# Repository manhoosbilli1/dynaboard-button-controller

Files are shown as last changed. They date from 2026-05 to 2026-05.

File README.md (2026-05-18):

# DynaButton

Dynaboard - STM32F103 multi-button HID/control interface with USB-C and high-density I/O

## At a Glance

- **Status**: Routed
- **Board size**: 48.31 x 52.88 mm
- **Layers**: 4
- **Components**: 68
- **Key ICs**:
  - U1: STM32F103C8T6
  - U2: U_REG LD1117S50TR_SOT223
  - U3: AMS1117
  - U4: 74LVC2G241

## Schematic

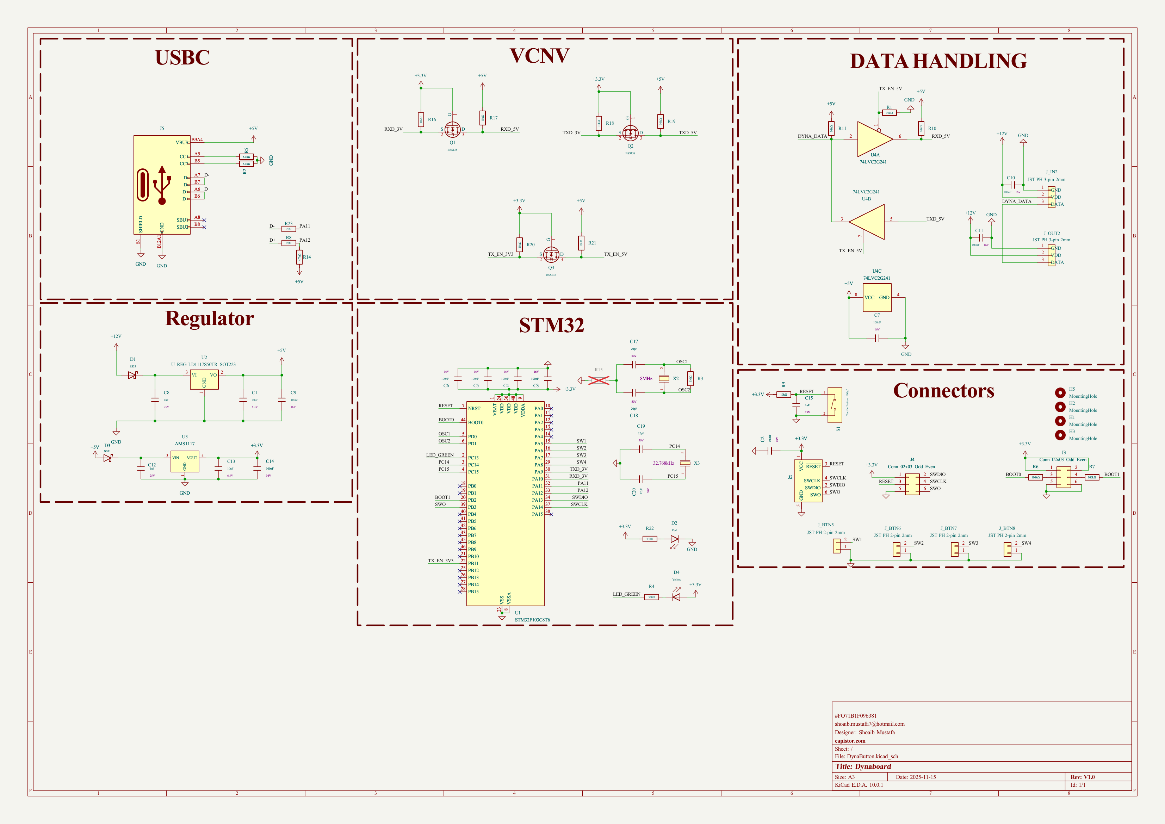
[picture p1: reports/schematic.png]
Schematic


Full PDF: [reports/schematic.pdf](reports/schematic.pdf)

## Component Roles

- **STM32F103C8T6** (U1) - main MCU (ARM Cortex-M3, 72 MHz); handles button matrix scanning and USB HID
- **74LVC2G241** (U4) - dual buffer/line driver for clean digital I/O signaling on the button outputs
- **LD1117S50TR** (U2) - 5 V LDO for peripheral rail
- **AMS1117** (U3) - 3.3 V LDO for the STM32 core
- **BSS138** x3 (Q1-Q3) - small-signal N-MOSFETs for level shifting / open-drain signaling between 3.3 V MCU and 5 V peripherals
- **X50328MSB2GI** - 8 MHz crystal for STM32 system clock
- **USB-Type-C 16-pin** connector for power + data
- **SS33 Schottky** x2 (D1, D3) - reverse-polarity protection / freewheel diodes
- **JST-PH 2 mm** connectors for daisy-chained external buttons (J_BTN5-J_BTN8) and pass-through I/O (J_IN2, J_OUT2)

## PCB

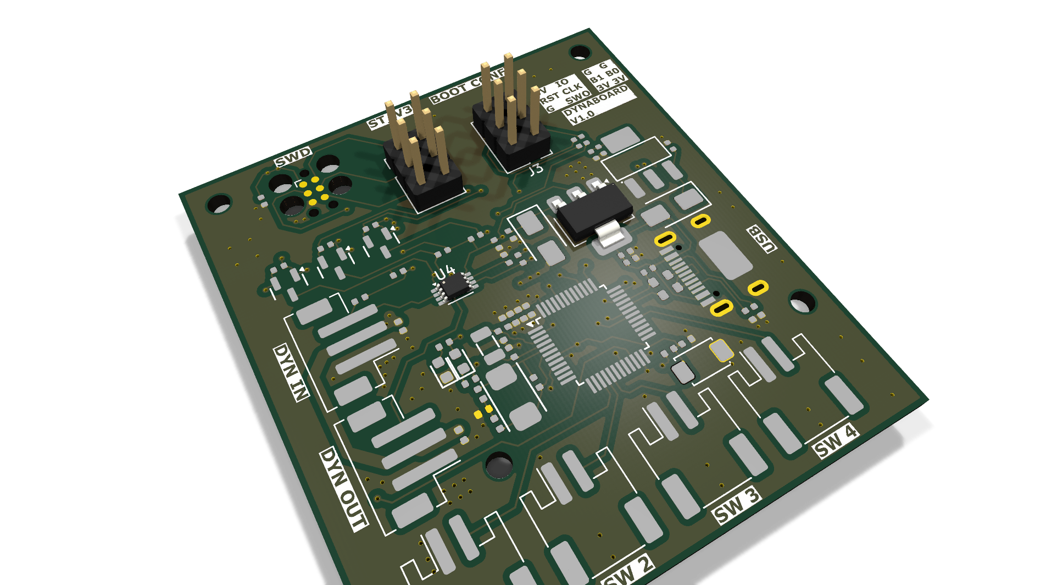
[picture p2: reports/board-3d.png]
3D top


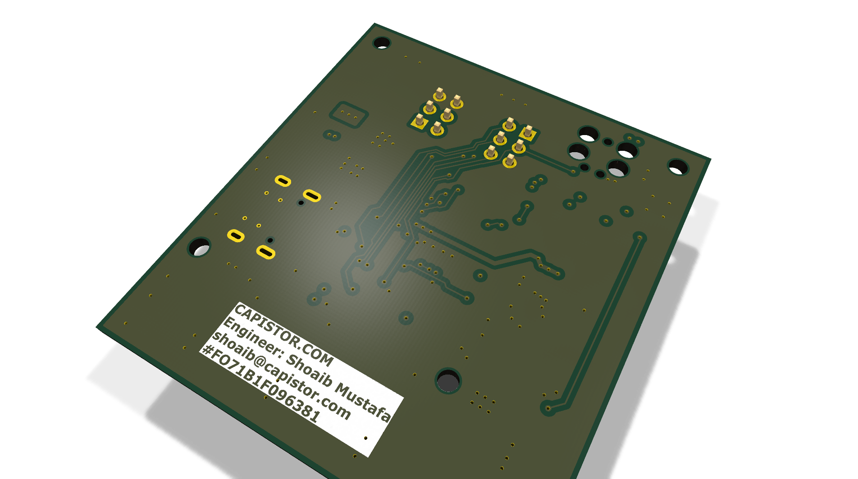
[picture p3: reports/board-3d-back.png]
3D bottom


**Top copper**

PCB top

**Bottom copper**

PCB bottom

## Bill of Materials

| Refs | Value | Footprint | Qty | MPN | LCSC |
|---|---|---|----:|-----|---|
| C1,C13 | 10uF | PCM_JLCPCB:C_0402 | 2 |  | [C15525](https://www.lcsc.com/product-detail/_C15525.html) |
| C2-C7,C9-C11,C14 | 100nF | PCM_JLCPCB:C_0402 | 10 |  | [C1525](https://www.lcsc.com/product-detail/_C1525.html) |
| C8,C12,C15 | 1uF | PCM_JLCPCB:C_0402 | 3 |  | [C52923](https://www.lcsc.com/product-detail/_C52923.html) |
| C17,C18 | 20pF | PCM_JLCPCB:C_0402 | 2 |  | [C1554](https://www.lcsc.com/product-detail/_C1554.html) |
| C19,C20 | 12pF | PCM_JLCPCB:C_0402 | 2 |  | [C1547](https://www.lcsc.com/product-detail/_C1547.html) |
| D1,D3 | SS33 | PCM_JLCPCB:D_SMA | 2 |  | [C28646294](https://www.lcsc.com/product-detail/_C28646294.html) |
| D2 | Red | PCM_JLCPCB:D_0603 | 1 |  | [C2286](https://www.lcsc.com/product-detail/_C2286.html) |
| D4 | Yellow | PCM_JLCPCB:D_0603 | 1 |  | [C89811](https://www.lcsc.com/product-detail/_C89811.html) |
| J3,J4 | Conn_02x03_Odd_Even | Connector_PinHeader_2.54mm:PinHeader_2x03_P2.54mm_Vertical | 2 |  |  |
| J5 | Connector, USB-TYPE-C-16P | PCM_JLCPCB:TYPE-C-SMD_HX-TYPE-C-16PIN | 1 |  | [C2927039](https://www.lcsc.com/product-detail/_C2927039.html) |
| J_BTN5-J_BTN8 | JST PH 2-pin 2mm | Connector_JST:JST_PH_S2B-PH-SM4-TB_1x02-1MP_P2.00mm_Horizontal | 4 |  |  |
| J_IN2,J_OUT2 | JST PH 3-pin 2mm | Connector_JST:JST_PH_B3B-PH-SM4-TB_1x03-1MP_P2.00mm_Vertical | 2 |  |  |
| Q1-Q3 | BSS138 | PCM_JLCPCB:Q_SOT-23 | 3 |  | [C7420339](https://www.lcsc.com/product-detail/_C7420339.html) |
| R1,R9-R11,R16-R21 | 10kΩ | PCM_JLCPCB:R_0402 | 10 |  | [C25744](https://www.lcsc.com/product-detail/_C25744.html) |
| R2,R5 | 5.1kΩ | PCM_JLCPCB:R_0402 | 2 |  | [C25905](https://www.lcsc.com/product-detail/_C25905.html) |
| R3 | 1MΩ | PCM_JLCPCB:R_0402 | 1 |  | [C26083](https://www.lcsc.com/product-detail/_C26083.html) |
| R4,R22 | 330Ω | PCM_JLCPCB:R_0402 | 2 |  | [C25104](https://www.lcsc.com/product-detail/_C25104.html) |
| R6,R7 | 100kΩ | PCM_JLCPCB:R_0402 | 2 |  | [C25741](https://www.lcsc.com/product-detail/_C25741.html) |
| R8,R23 | 20Ω | PCM_JLCPCB:R_0603 | 2 |  | [C22950](https://www.lcsc.com/product-detail/_C22950.html) |
| R14 | 4.7kΩ | PCM_JLCPCB:R_0402 | 1 |  | [C25900](https://www.lcsc.com/product-detail/_C25900.html) |
| S1 | Tactile Button, 160gf | PCM_JLCPCB:SW_TS-1088-AR02016 | 1 |  | [C720477](https://www.lcsc.com/product-detail/_C720477.html) |
| U1 | STM32F103C8T6 | PCM_JLCPCB:LQFP-48_7x7mm_P0.5mm | 1 |  | [C8734](https://www.lcsc.com/product-detail/_C8734.html) |
| U2 | U_REG LD1117S50TR_SOT223 | Package_TO_SOT_SMD:SOT-223-3_TabPin2 | 1 |  |  |
| U3 | AMS1117 | PCM_JLCPCB:SOT-223-3_L6.5-W3.4-P2.30-LS7.0-BR | 1 |  | [C6186](https://www.lcsc.com/product-detail/_C6186.html) |
| U4 | 74LVC2G241 | Package_SO:VSSOP-8_3x3mm_P0.65mm | 1 |  |  |
| X2 | X50328MSB2GI | PCM_JLCPCB:CRYSTAL-SMD_L5.0-W3.2 | 1 |  | [C115962](https://www.lcsc.com/product-detail/_C115962.html) |
| X3 | Q13FC1350000400 | PCM_JLCPCB:FC-135R_L3.2-W1.5 | 1 |  | [C32346](https://www.lcsc.com/product-detail/_C32346.html) |

_5 of 27 line items don't have an LCSC code in the schematic - search [LCSC](https://www.lcsc.com/) or [JLC parts search](https://jlcsearch.tscircuit.com/) by MPN or footprint when sourcing._

## Files

- `DynaButton.kicad_pro` - KiCad project
- `DynaButton.kicad_sch` - schematic source
- `DynaButton.kicad_pcb` - PCB layout source
- `reports/schematic.pdf` - full schematic (printable)
- `reports/bom.csv` - bill of materials
- `reports/pcb-top.svg`, `reports/pcb-bottom.svg` - copper artwork
- `reports/board-stats.json` - KiCad-generated board statistics

---

_Renders and metadata auto-generated by `Backup-KiCadProject.ps1` using KiCad 10.0._

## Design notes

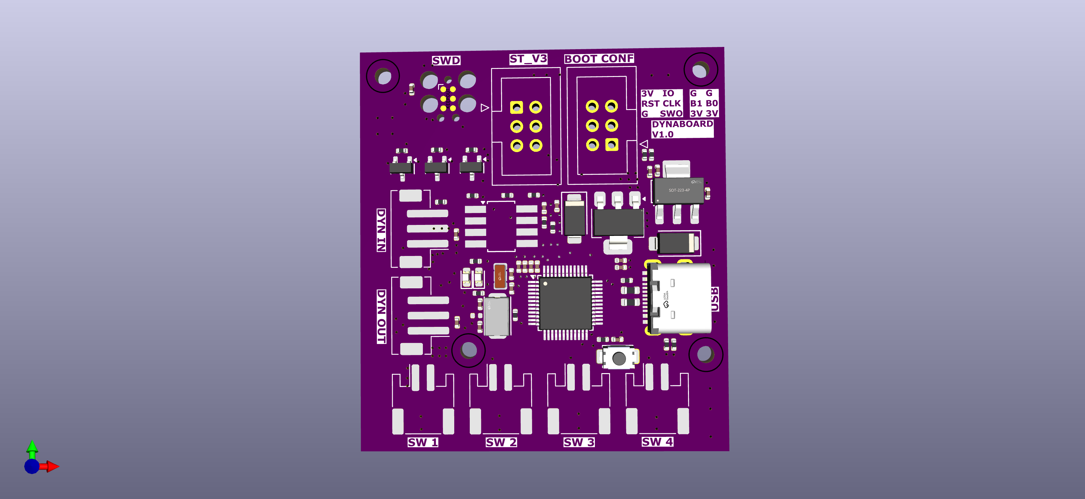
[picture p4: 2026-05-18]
DynaButton.png

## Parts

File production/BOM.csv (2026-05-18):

Designator | Footprint | Quantity | Value | LCSC Part #
C1, C13 | C_0402 | 2 | 10uF | C15525
C10, C11, C14, C2, C3, C4, C5, C6, C7, C9 | C_0402 | 10 | 100nF | C1525
C12, C15, C8 | C_0402 | 3 | 1uF | C52923
C17, C18 | C_0402 | 2 | 20pF | C1554
C19, C20 | C_0402 | 2 | 12pF | C1547
D1, D3 | D_SMA | 2 | SS33 | C28646294
D2 | D_0603 | 1 | Red | C2286
D4 | D_0603 | 1 | Yellow | C89811
J3, J4 | PinHeader_2x03_P2.54mm_Vertical | 2 | Conn_02x03_Odd_Even
J5 | TYPE-C-SMD_HX-TYPE-C-16PIN | 1 | Connector, USB-TYPE-C-16P | C2927039
J_BTN5, J_BTN6, J_BTN7, J_BTN8 | JST_PH_S2B-PH-SM4-TB_1x02-1MP_P2.00mm_Horizontal | 4 | JST PH 2-pin 2mm
J_IN2, J_OUT2 | JST_PH_B3B-PH-SM4-TB_1x03-1MP_P2.00mm_Vertical | 2 | JST PH 3-pin 2mm
Q1, Q2, Q3 | Q_SOT-23 | 3 | BSS138 | C7420339
R1, R10, R11, R16, R17, R18, R19, R20, R21, R9 | R_0402 | 10 | 10kΩ | C25744
R14 | R_0402 | 1 | 4.7kΩ | C25900
R2, R5 | R_0402 | 2 | 5.1kΩ | C25905
R22, R4 | R_0402 | 2 | 330Ω | C25104
R23, R8 | R_0603 | 2 | 20Ω | C22950
R3 | R_0402 | 1 | 1MΩ | C26083
R6, R7 | R_0402 | 2 | 100kΩ | C25741
S1 | SW_TS-1088-AR02016 | 1 | Tactile Button, 160gf | C720477
U1 | LQFP-48_7x7mm_P0.5mm | 1 | STM32F103C8T6 | C8734
U2 | SOT-223-3_TabPin2 | 1 | U_REG LD1117S50TR_SOT223
U3 | SOT-223-3_L6.5-W3.4-P2.30-LS7.0-BR | 1 | AMS1117 | C6186
U4 | VSSOP-8_2.3x2mm_P0.5mm | 1 | 74LVC2G241
X2 | CRYSTAL-SMD_L5.0-W3.2 | 1 | X50328MSB2GI | C115962
X3 | FC-135R_L3.2-W1.5 | 1 | Q13FC1350000400 | C32346

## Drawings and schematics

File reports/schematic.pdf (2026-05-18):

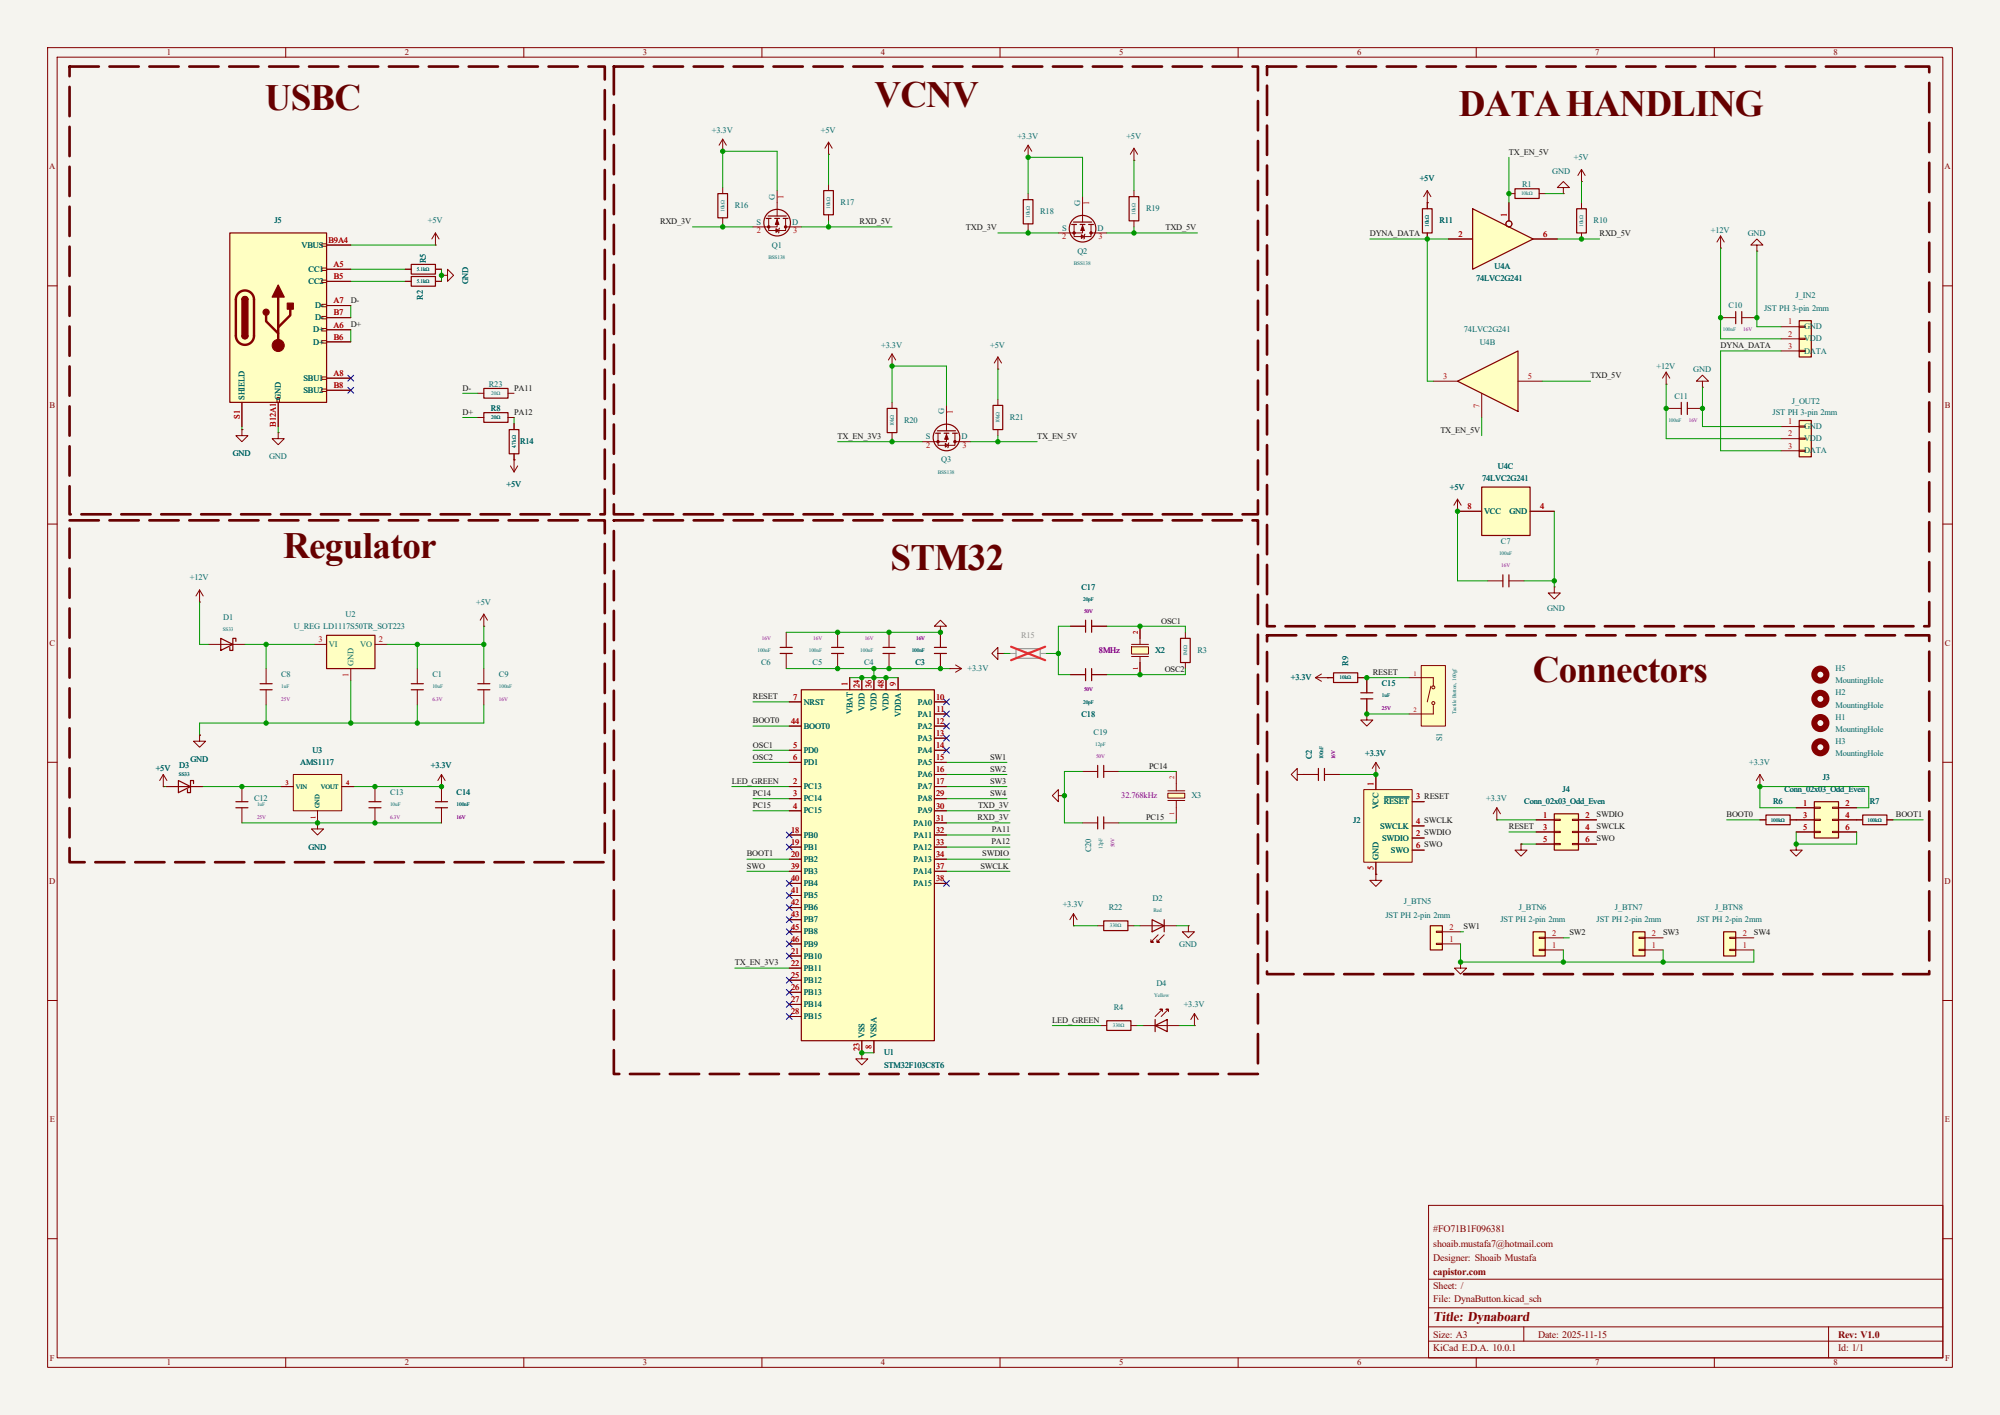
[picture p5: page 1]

9 PA0 10 PA1 11 PA2 12 PA3 13 PA4 14 PA5 15 PA6 16 PA7 17 PB0 18 PB1 19 PB2 20 PB10 21 PB11 22 VSS 23 VDD 24 PB12 25 PB13 26 PB14 27 PB15 28 PA8 29 PA9 30 PA10 31 PA11 32 PA12 33 PA13 34 VDD 36 PA14 37 PA15 38 PB3 39 PB4 40 PB5 41 PB6 42 PB7 43 BOOT0 44 PB8 45 PB9 46 VDD 48 C3

9 PA0 10 PA1 11 PA2 12 PA3 13 PA4 14 PA5 15 PA6 16 PA7 17 PB0 18 PB1 19 PB2 20 PB10 21 PB11 22 VSS 23 VDD 24 PB12 25 PB13 26 PB14 27 PB15 28 PA8 29 PA9 30 PA10 31 PA11 32 PA12 33 PA13 34 VDD 36 PA14 37 PA15 38 PB3 39 PB4 40 PB5 41 PB6 42 PB7 43 BOOT0 44 PB8 45 PB9 46 VDD 48 U1 STM32F103C8T6 R4

1 SWDIO 2 RESET 3 SWCLK 4 GND
+3.3V VCC

shoaib.mustafa7@hotmail.com
Designer: Shoaib Mustafa
File: DynaButton.kicad_sch Sheet: / capistor.com

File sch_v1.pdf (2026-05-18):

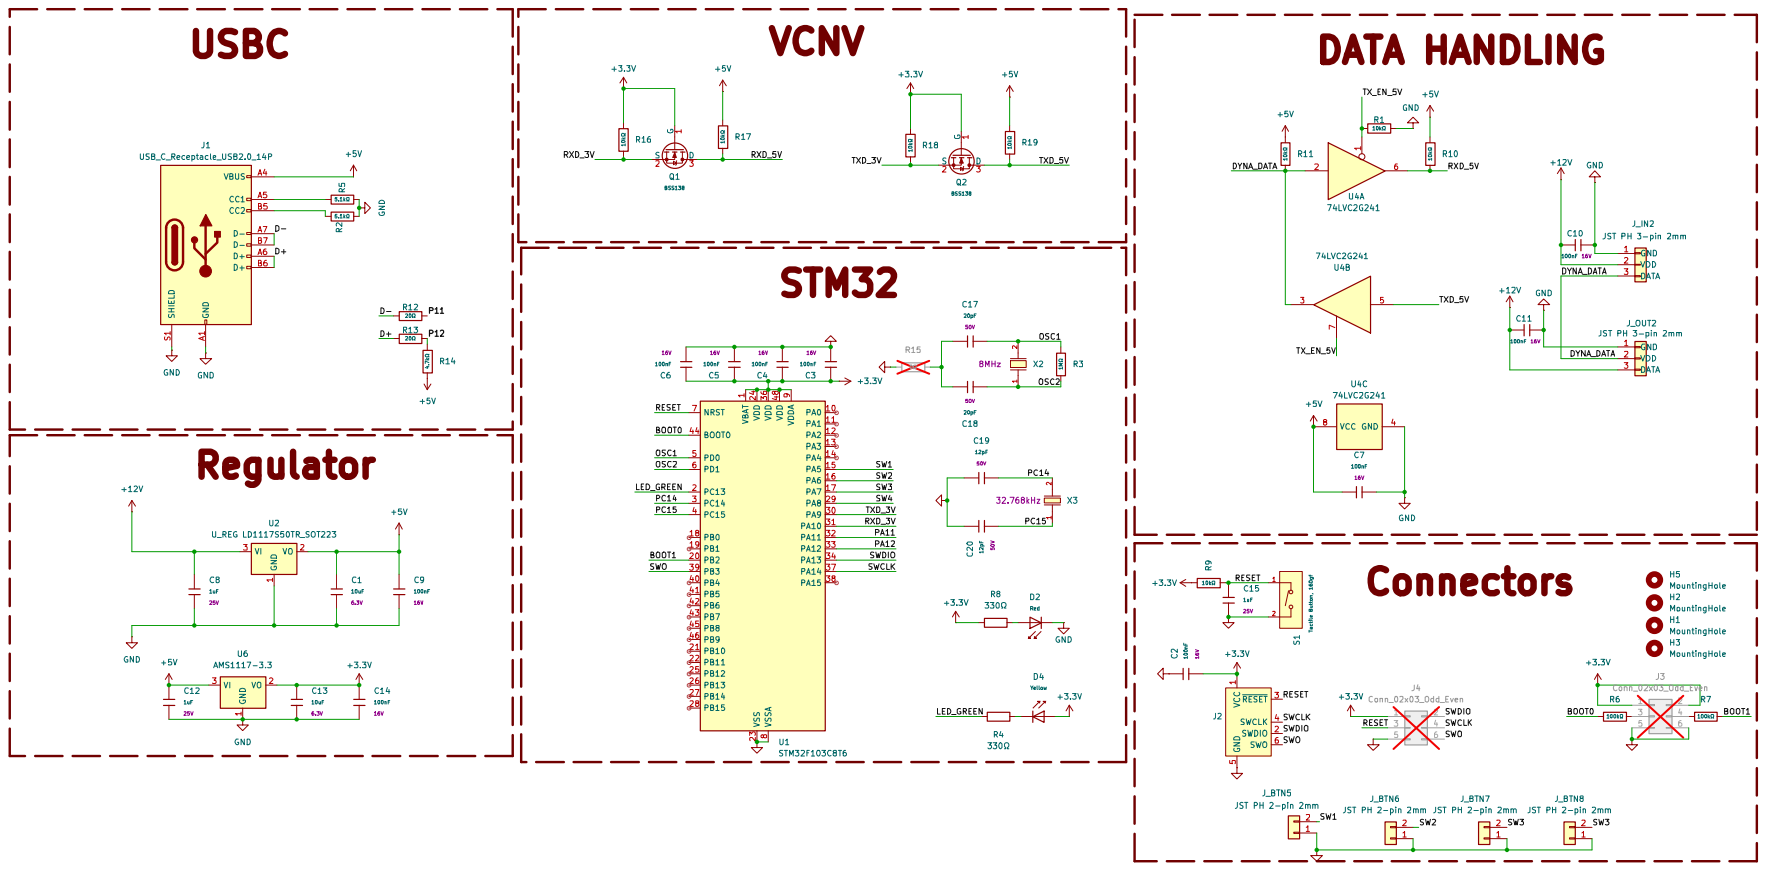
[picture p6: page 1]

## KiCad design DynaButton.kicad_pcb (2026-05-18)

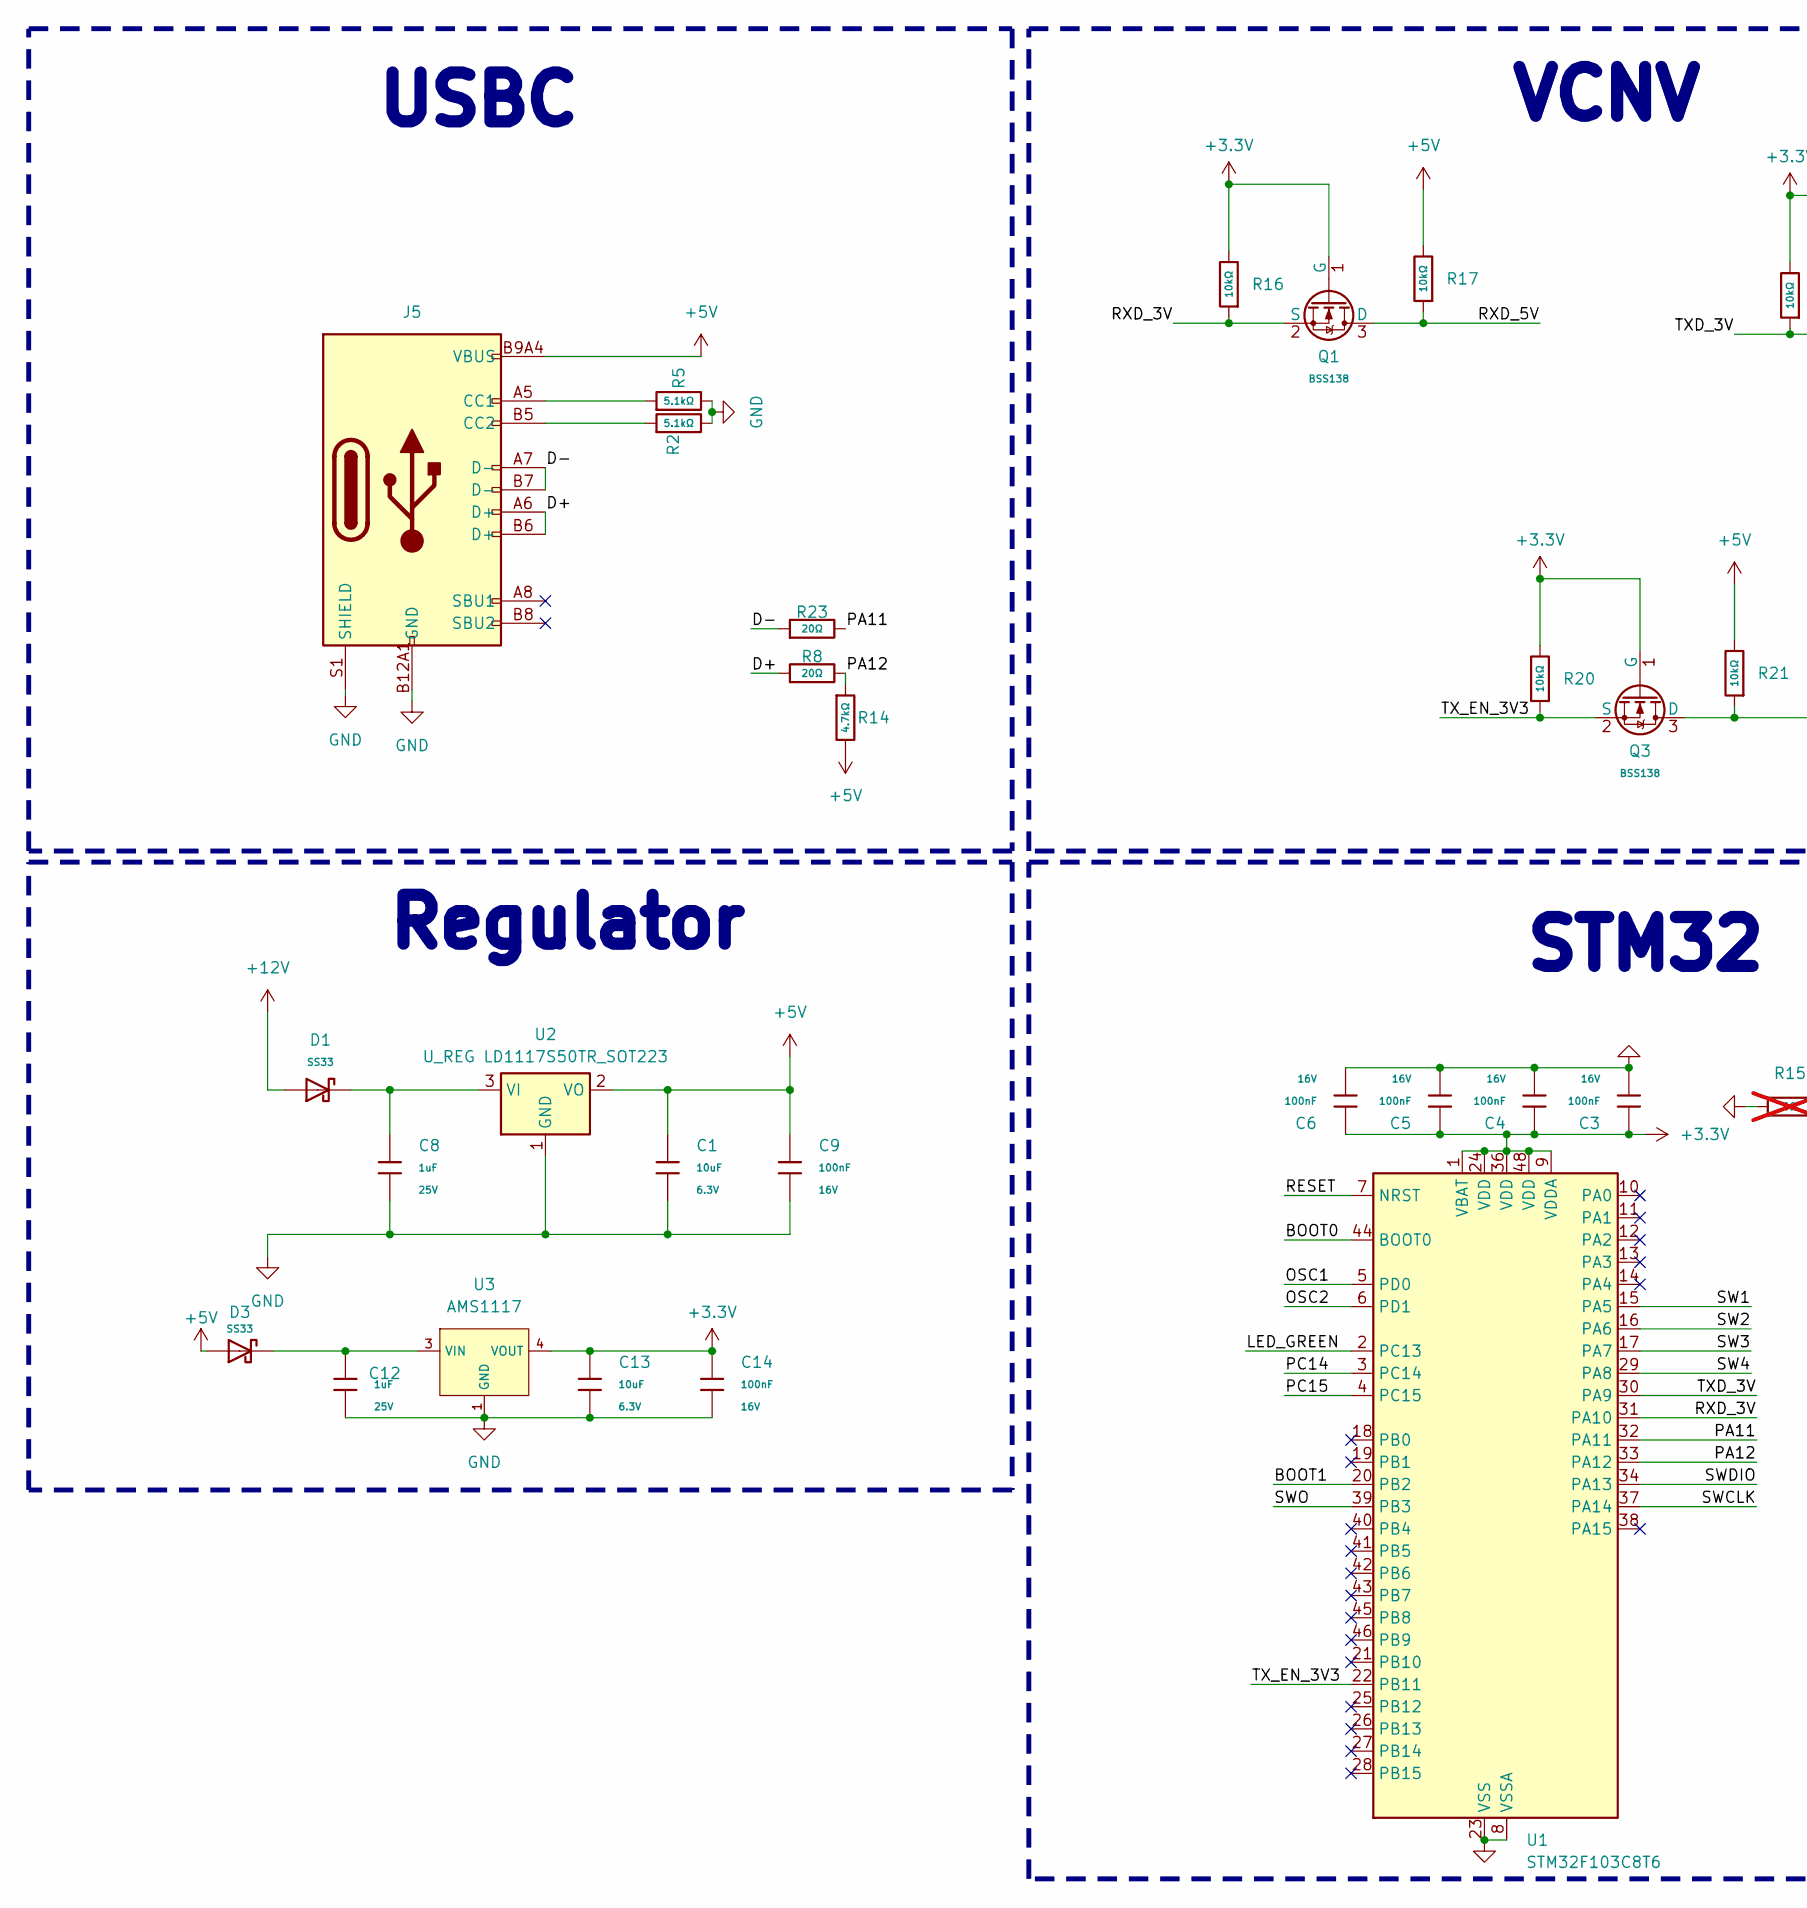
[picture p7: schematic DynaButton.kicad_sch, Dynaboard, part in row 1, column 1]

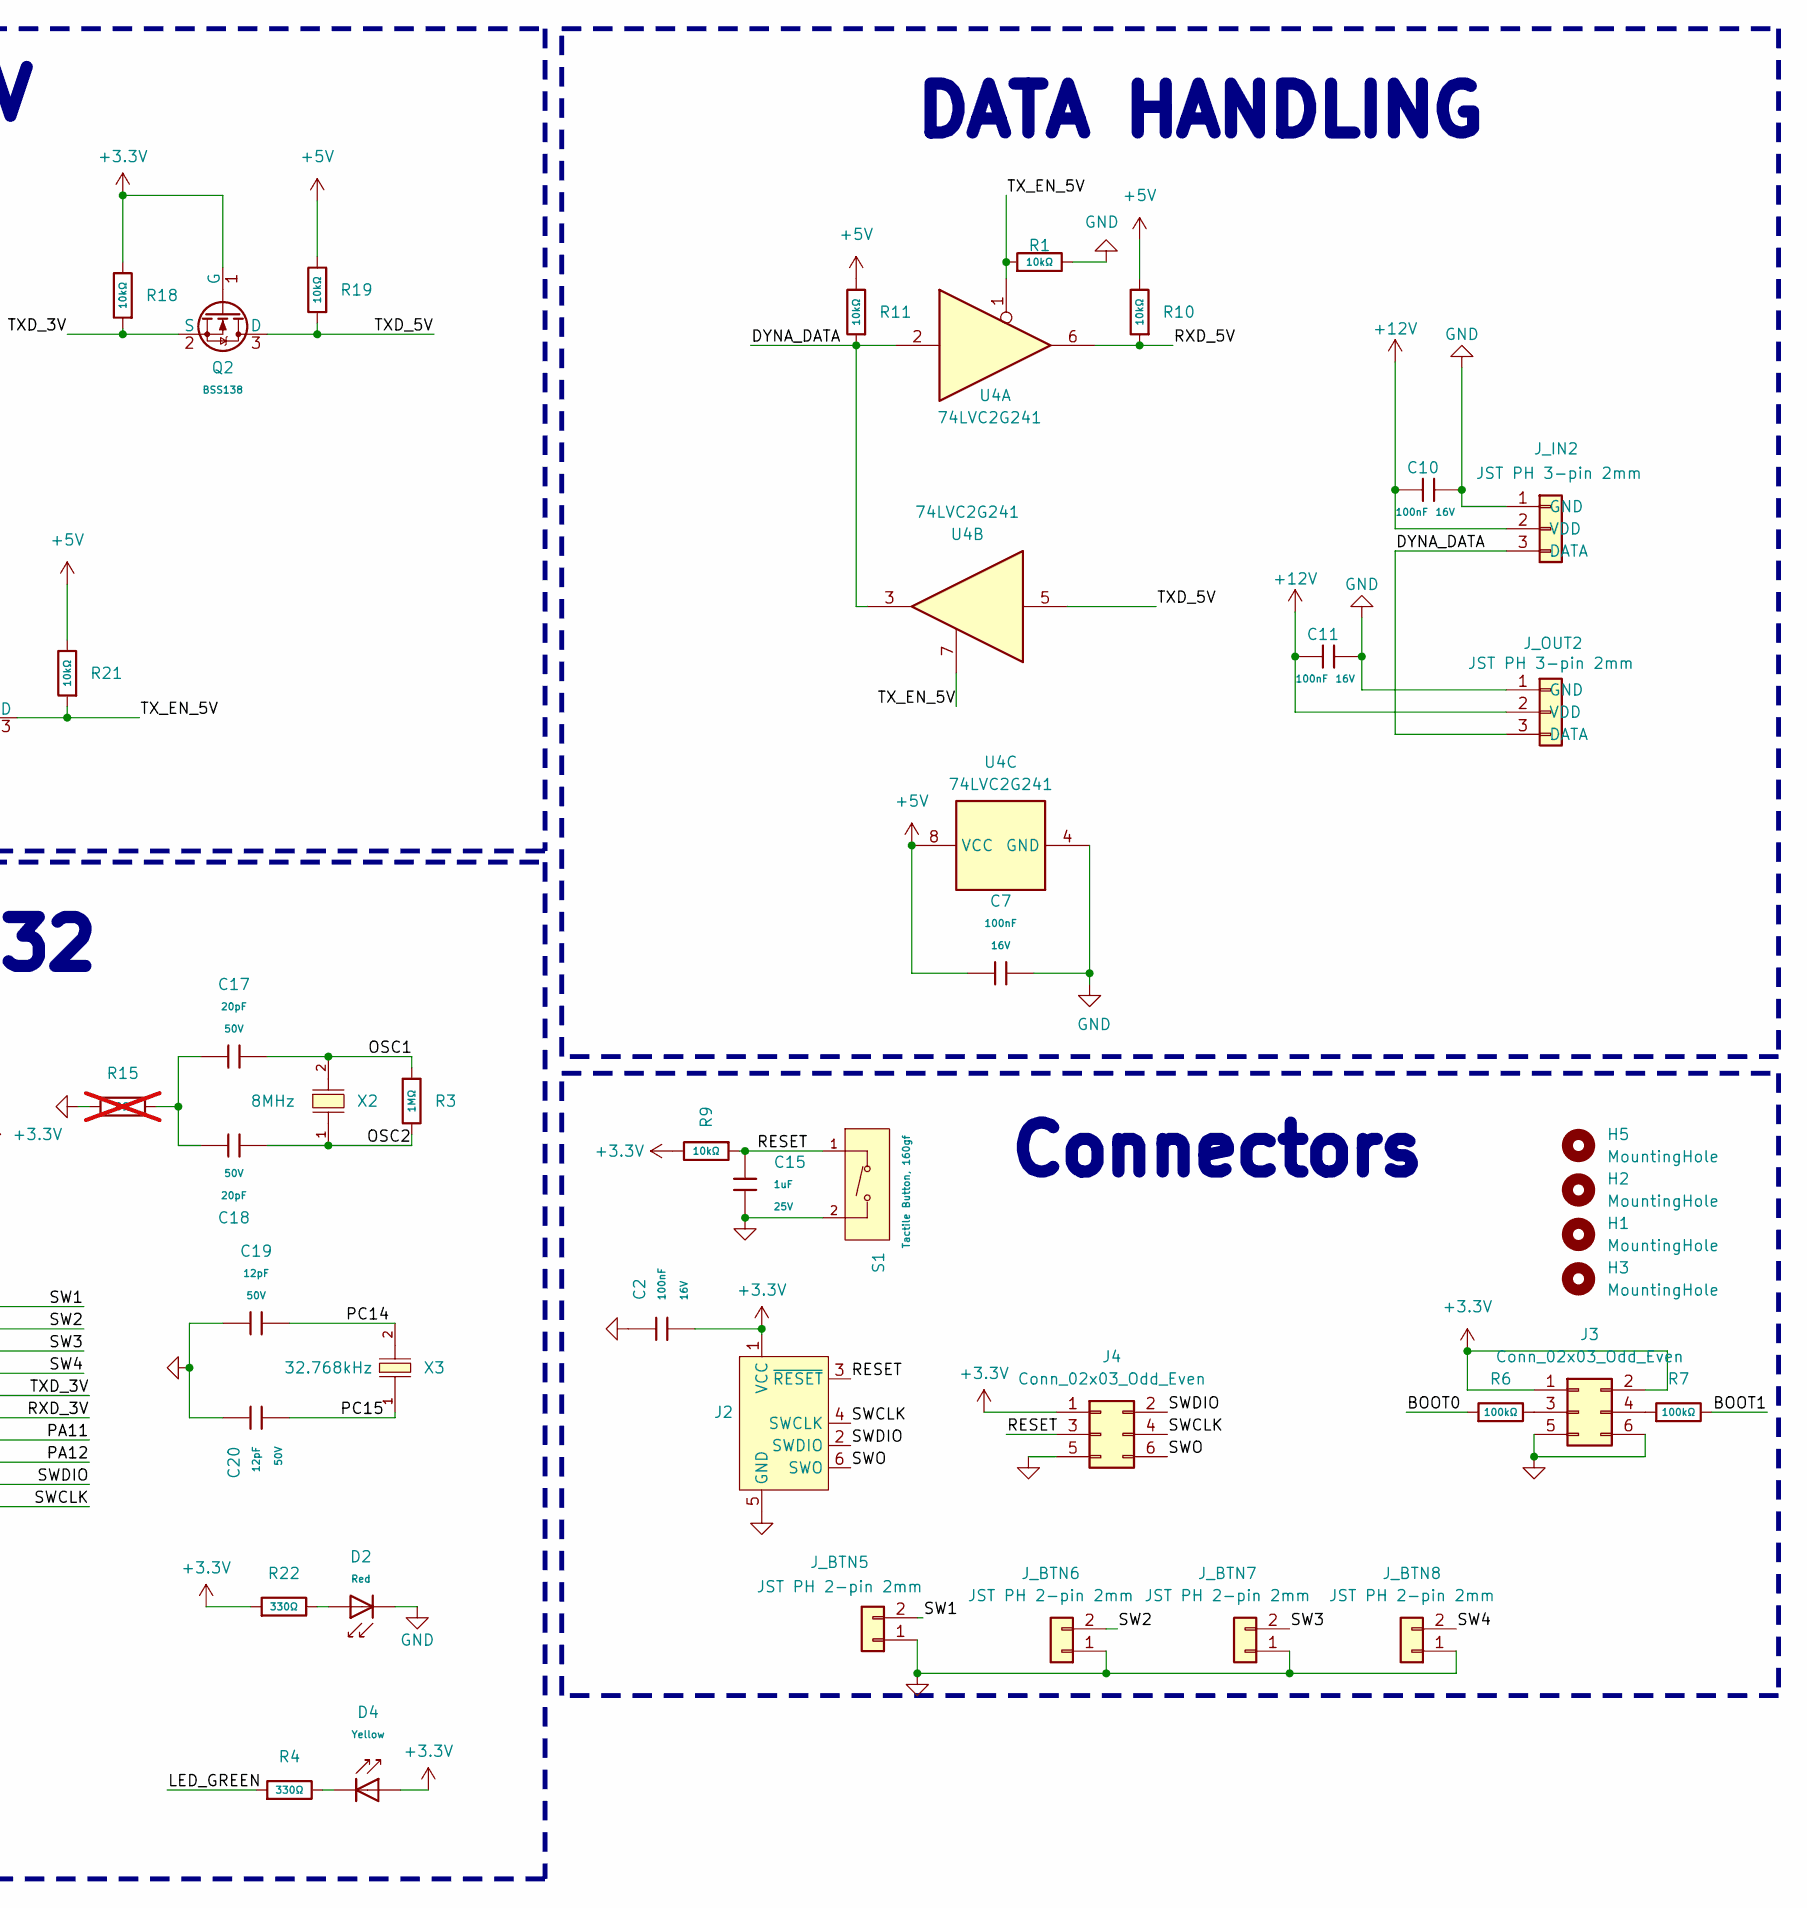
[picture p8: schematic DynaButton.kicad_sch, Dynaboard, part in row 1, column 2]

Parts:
C1, C13: 10uF; C_0402; Voltage Rated 6.3V; Tolerance ±20%; Part CL05A106MQ5NUNC; LCSC C15525
C2, C3, C4, C5, C6, C7, C9, C10, C11, C14: 100nF; C_0402; Voltage Rated 16V; Tolerance ±10%; Part CL05B104KO5NNNC; LCSC C1525
C8, C12, C15: 1uF; C_0402; Voltage Rated 25V; Tolerance ±10%; Part CL05A105KA5NQNC; LCSC C52923
C17, C18: 20pF; C_0402; Voltage Rated 50V; Tolerance ±5%; Part 0402CG200J500NT; LCSC C1554
C19, C20: 12pF; C_0402; Voltage Rated 50V; Tolerance ±5%; Part 0402CG120J500NT; LCSC C1547
D1, D3: SS33; D_SMA; Part SS33; LCSC C28646294
D2: Red; D_0603; Part KT-0603R; LCSC C2286
D4: Yellow; D_0603; Forward Voltage (VF) 1.6V~2.6V; Part NCD0603Y2; LCSC C89811
H1, H2, H3, H5: MountingHole; MountingHole_2.2mm_M2
J2: Conn_ARM_SWD_TagConnect_TC2030; Tag-Connect_TC2030-IDC-FP_2x03_P1.27mm_Vertical
J3, J4: Conn_02x03_Odd_Even; PinHeader_2x03_P2.54mm_Vertical
J5: Connector, USB-TYPE-C-16P; TYPE-C-SMD_HX-TYPE-C-16PIN; LCSC C2927039
J_BTN5, J_BTN6, J_BTN7, J_BTN8: JST PH 2-pin 2mm; JST_PH_S2B-PH-SM4-TB_1x02-1MP_P2.00mm_Horizontal; PART NUMBER C295747
J_IN2: JST PH 3-pin 2mm; JST_PH_B3B-PH-SM4-TB_1x03-1MP_P2.00mm_Vertical; JLCPCB PART # C160353
J_OUT2: JST PH 3-pin 2mm; JST_PH_B3B-PH-SM4-TB_1x03-1MP_P2.00mm_Vertical; JLCPCB PART # C160353
Q1, Q2, Q3: BSS138; Q_SOT-23; Part BSS138; LCSC C7420339
R1, R9, R10, R11, R16, R17, R18, R19, R20, R21: 10kΩ; R_0402; Overload Voltage (Max) 50V; Tolerance ±1%; Part 0402WGF1002TCE; LCSC C25744
R2, R5: 5.1kΩ; R_0402; Overload Voltage (Max) 50V; Tolerance ±1%; Part 0402WGF5101TCE; LCSC C25905
R3: 1MΩ; R_0402; Overload Voltage (Max) 50V; Tolerance ±1%; Part 0402WGF1004TCE; LCSC C26083
R4, R22: 330Ω; R_0402; Overload Voltage (Max) 50V; Tolerance ±1%; Part 0402WGF3300TCE; LCSC C25104
R6, R7: 100kΩ; R_0402; Overload Voltage (Max) 50V; Tolerance ±1%; Part 0402WGF1003TCE; LCSC C25741
R8, R23: 20Ω; R_0603; Overload Voltage (Max) 75V; Tolerance ±1%; Part 0603WAF200JT5E; LCSC C22950
R14: 4.7kΩ; R_0402; Overload Voltage (Max) 50V; Tolerance ±1%; Part 0402WGF4701TCE; LCSC C25900
R15: 0Ω; R_0402; Overload Voltage (Max) 50V; Tolerance ±1%; Part 0402WGF0000TCE; LCSC C17168; not fitted
S1: Tactile Button, 160gf; SW_TS-1088-AR02016; Voltage Rating (Dc) 12V; Part TS-1088-AR02016; LCSC C720477
U1: STM32F103C8T6; LQFP-48_7x7mm_P0.5mm; Operating Voltage Range 2V~3.6V; Low Voltage Detection T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 2V~3.6V; Part STM32F103C8T6; LCSC C8734
U2: U_REG LD1117S50TR_SOT223; SOT-223-3_TabPin2; PART NUMBER C134077
U3: AMS1117; SOT-223-3_L6.5-W3.4-P2.30-LS7.0-BR; Output Voltage 3.3V; Dropout Voltage 1.3V@(800mA); Part AMS1117-3.3; LCSC C6186
U4: 74LVC2G241; VSSOP-8_3x3mm_P0.65mm
X2: X50328MSB2GI; CRYSTAL-SMD_L5.0-W3.2; Frequency Tolerance ±10ppm; Part X50328MSB2GI; LCSC C115962
X3: Q13FC1350000400; FC-135R_L3.2-W1.5; Frequency Tolerance ±20ppm; Part Q13FC13500004; LCSC C32346

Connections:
+3.3V: C2.2, C3.1, C4.1, C5.1, C6.1, C13.1, C14.1, D4.2, J2.1 (VCC), J3.1, J3.2, J4.1, Q1.1 (G), Q2.1 (G), Q3.1 (G), R9.2, R16.2, R18.2, R20.2, R22.1, U1.1 (VBAT), U1.9 (VDDA), U1.24 (VDD), U1.36 (VDD), U1.48 (VDD), U3.2 (VOUT), U3.4 (VOUT)
+5V: C1.1, C7.1, C9.1, D3.2, J5.A9B4 (VBUS), J5.B9A4 (VBUS), R10.2, R11.2, R14.2, R17.2, R19.2, R21.2, U2.2 (VO), U4.8 (VCC)
+12V: C10.2, C11.2, D1.2, J_IN2.2 (VDD), J_OUT2.2 (VDD)
/BOOT0: R6.1, U1.44 (BOOT0)
/BOOT1: R7.2, U1.20 (PB2)
/D+: J5.A6 (D+), J5.B6 (D+), R8.1
/D-: J5.A7 (D-), J5.B7 (D-), R23.1
/DYNA_DATA: J_IN2.3 (DATA), J_OUT2.3 (DATA), R11.1, U4.2, U4.3
/LED_GREEN: R4.1, U1.2 (PC13)
/OSC1: C17.2, R3.1, U1.5 (PD0), X2.2
/OSC2: C18.2, R3.2, U1.6 (PD1), X2.1
/PA11: R23.2, U1.32 (PA11)
/PA12: R8.2, R14.1, U1.33 (PA12)
/PC14: C19.2, U1.3 (PC14), X3.2
/PC15: C20.1, U1.4 (PC15), X3.1
/RESET: C15.1, J2.3 (~RESET), J4.3, R9.1, S1.1 (A), U1.7 (NRST)
/RXD_3V: Q1.2 (S), R16.1, U1.31 (PA10)
/RXD_5V: Q1.3 (D), R10.1, R17.1, U4.6
/SW1: J_BTN5.2, U1.15 (PA5)
/SW2: J_BTN6.2, U1.16 (PA6)
/SW3: J_BTN7.2, U1.17 (PA7)
/SW4: J_BTN8.2, U1.29 (PA8)
/SWCLK: J2.4 (SWCLK), J4.4, U1.37 (PA14)
/SWDIO: J2.2 (SWDIO), J4.2, U1.34 (PA13)
/SWO: J2.6 (SWO), J4.6, U1.39 (PB3)
/TXD_3V: Q2.2 (S), R18.1, U1.30 (PA9)
/TXD_5V: Q2.3 (D), R19.1, U4.5
/TX_EN_3V3: Q3.2 (S), R20.1, U1.22 (PB11)
/TX_EN_5V: Q3.3 (D), R1.1, R21.1, U4.1, U4.7
GND: C1.2, C2.1, C3.2, C4.2, C5.2, C6.2, C7.2, C8.2, C9.2, C10.1, C11.1, C12.2, C13.2, C14.2, C15.2, C19.1, C20.2, D2.1, J2.5 (GND), J3.5, J3.6, J4.5, J5.A12B1 (GND), J5.B12A1 (GND), J5.S1 (SHIELD), J_BTN5.1, J_BTN6.1, J_BTN7.1, J_BTN8.1, J_IN2.1 (GND), J_OUT2.1 (GND), R1.2, R2.2, R5.2, R15.1, S1.2 (B), U1.8 (VSSA), U1.23 (VSS), U1.35 (VSS), U1.47 (VSS), U2.1 (GND), U3.1 (GND), U4.4 (GND)
unnamed: C17.1, C18.1, R15.2
unnamed: D2.2, R22.2
unnamed: D4.1, R4.2
unnamed: J3.3, R6.2
unnamed: J3.4, R7.1
unnamed: J5.A5 (CC1), R5.1
unnamed: J5.B5 (CC2), R2.1
unnamed: C8.1, D1.1, U2.3 (VI)
unnamed: C12.1, D3.1, U3.3 (VIN)

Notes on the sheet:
Regulator
DATA HANDLING
USBC
STM32
Connectors
VCNV

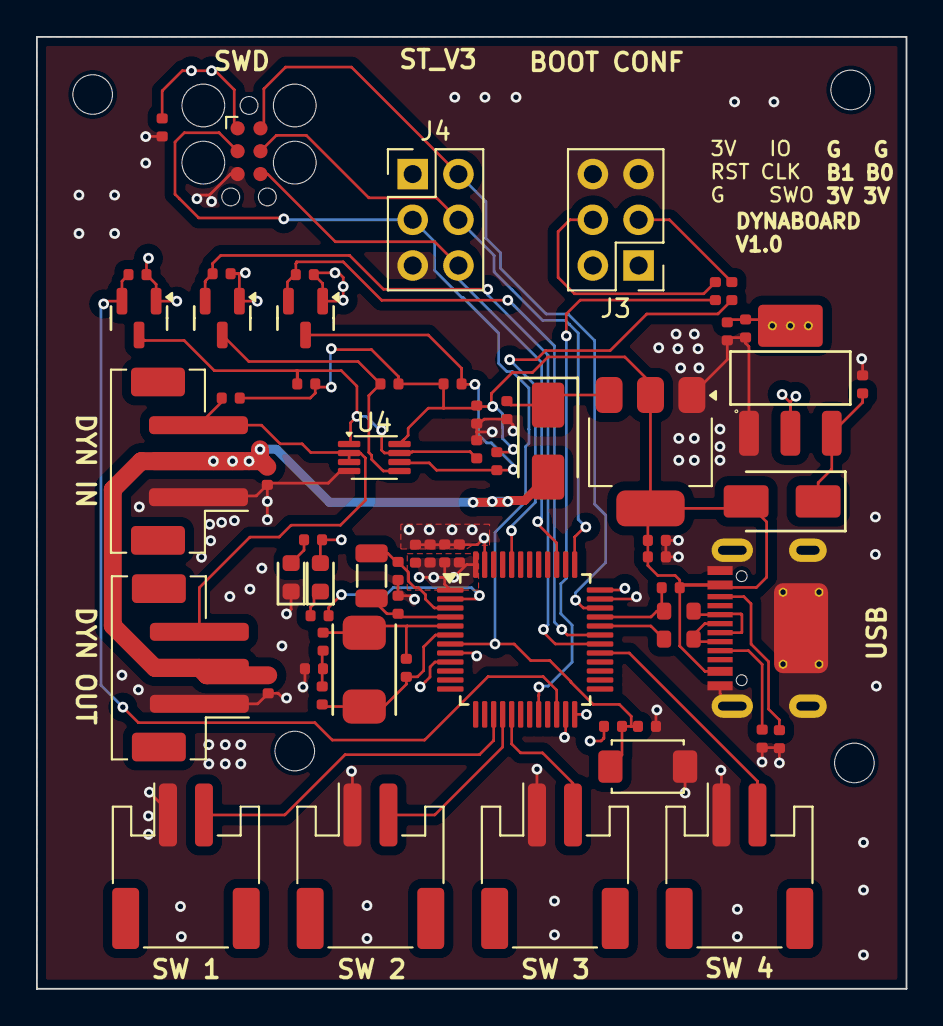
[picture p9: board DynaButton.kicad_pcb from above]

Board: 4 copper layers, 48.3 x 52.9 mm, 68 parts (0 on the bottom side), 39 nets.

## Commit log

2026-05-18 Update backup artifacts
    [BOM.csv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]
2026-05-18 Enrich README: schematic PNG, component roles, BOM table
